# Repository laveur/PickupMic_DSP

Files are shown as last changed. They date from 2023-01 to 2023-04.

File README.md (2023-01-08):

# PickupMic_DSP
A Pickup Mic (Piezo) DSP Board

## Info
Based on a STM32F405 MCU, this allows you to connect up to four Piezo (Pickup Mics) To it and do some signal processing on it.

Produce_DanZhi SMT_Snapshot Top 2263802A_Y28 SMT02301071084998

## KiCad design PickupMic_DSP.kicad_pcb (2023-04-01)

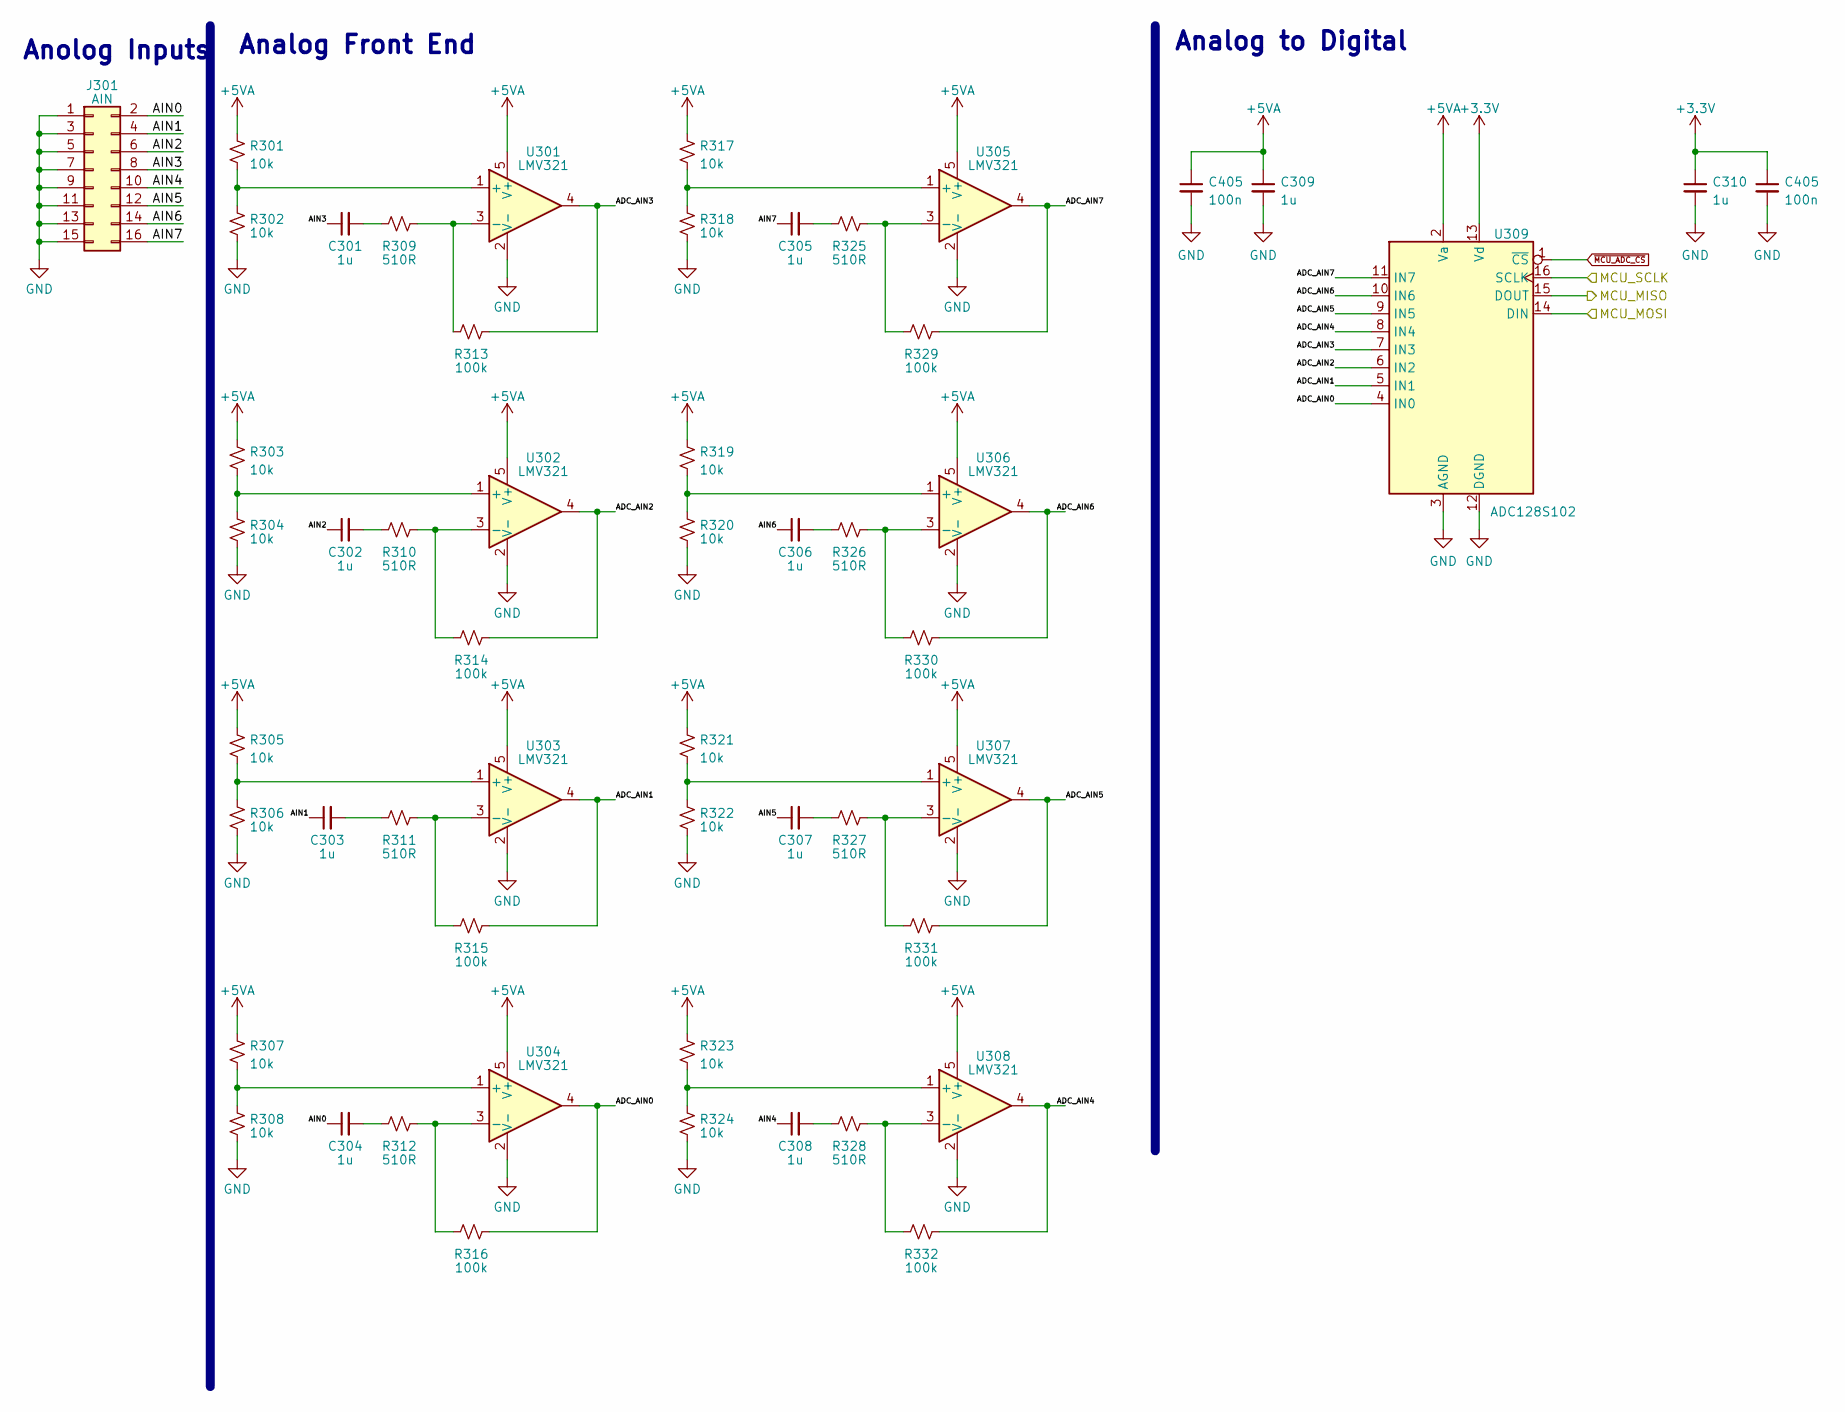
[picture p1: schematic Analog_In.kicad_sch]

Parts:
C301, C302, C303, C304, C305, C306, C307, C308, C309, C310: 1u; C_0402_1005Metric; LCSC C52923
C405: 100n; C_0402_1005Metric; LCSC C307331
J301: AIN; PinHeader_2x08_P2.54mm_Vertical
R301, R302, R303, R304, R305, R306, R307, R308, R317, R318, R319, R320, R321, R322, R323, R324: 10k; R_0402_1005Metric; LCSC C144807
R309, R310, R311, R312, R325, R326, R327, R328: 510R; R_0402_1005Metric; LCSC C25123
R313, R314, R315, R316, R329, R330, R331, R332: 100k; R_0402_1005Metric; LCSC C25086
U301, U302, U303, U304, U305, U306, U307, U308: LMV321; SOT-23-5; LCSC C7972
U309: ADC128S102; TSSOP-16_4.4x5mm_P0.65mm; LCSC C179666

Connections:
/Analog In/ADC_AIN0: R316.2, U304.4, U309.4 (IN0)
/Analog In/ADC_AIN1: R315.2, U303.4, U309.5 (IN1)
/Analog In/ADC_AIN2: R314.2, U302.4, U309.6 (IN2)
/Analog In/ADC_AIN4: R332.2, U308.4, U309.8 (IN4)
/Analog In/ADC_AIN5: R331.2, U307.4, U309.9 (IN5)
/Analog In/ADC_AIN6: R330.2, U306.4, U309.10 (IN6)
/Analog In/ADC_AIN7: R329.2, U305.4, U309.11 (IN7)
/Analog In/AIN0: C304.1, J301.2
/Analog In/AIN1: C303.1, J301.4
/Analog In/AIN2: C302.1, J301.6
/Analog In/AIN3: C301.1, J301.8
/Analog In/AIN4: C308.1, J301.10
/Analog In/AIN5: C307.1, J301.12
/Analog In/AIN6: C306.1, J301.14
/Analog In/AIN7: C305.1, J301.16
/Analog In/MCU_MISO: U309.15 (DOUT); also elsewhere on the board
/Analog In/MCU_MOSI: U309.14 (DIN); also elsewhere on the board
/Analog In/MCU_SCLK: U309.16 (SCLK); also elsewhere on the board
unnamed: C301.2, R309.2
unnamed: C302.2, R310.2
unnamed: C303.2, R311.2
unnamed: C304.2, R312.2
unnamed: C305.2, R325.2
unnamed: C306.2, R326.2
unnamed: C307.2, R327.2
unnamed: C308.2, R328.2
unnamed: R301.2, R302.2, U301.1 (+)
unnamed: R303.2, R304.1, U302.1 (+)
unnamed: R310.1, R314.1, U302.3 (-)
unnamed: R305.2, R306.2, U303.1 (+)
unnamed: R311.1, R315.1, U303.3 (-)
unnamed: R307.2, R308.2, U304.1 (+)
unnamed: R312.1, R316.1, U304.3 (-)
unnamed: R317.2, R318.2, U305.1 (+)
unnamed: R325.1, R329.1, U305.3 (-)
unnamed: R319.2, R320.2, U306.1 (+)
unnamed: R326.1, R330.1, U306.3 (-)
unnamed: R321.2, R322.2, U307.1 (+)
unnamed: R327.1, R331.1, U307.3 (-)
unnamed: R323.2, R324.2, U308.1 (+)
unnamed: R328.1, R332.1, U308.3 (-)
~MCU_ADC_CS: U309.1 (~CS); also elsewhere on the board

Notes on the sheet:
Analog Front End
Analog to Digital
Anolog Inputs

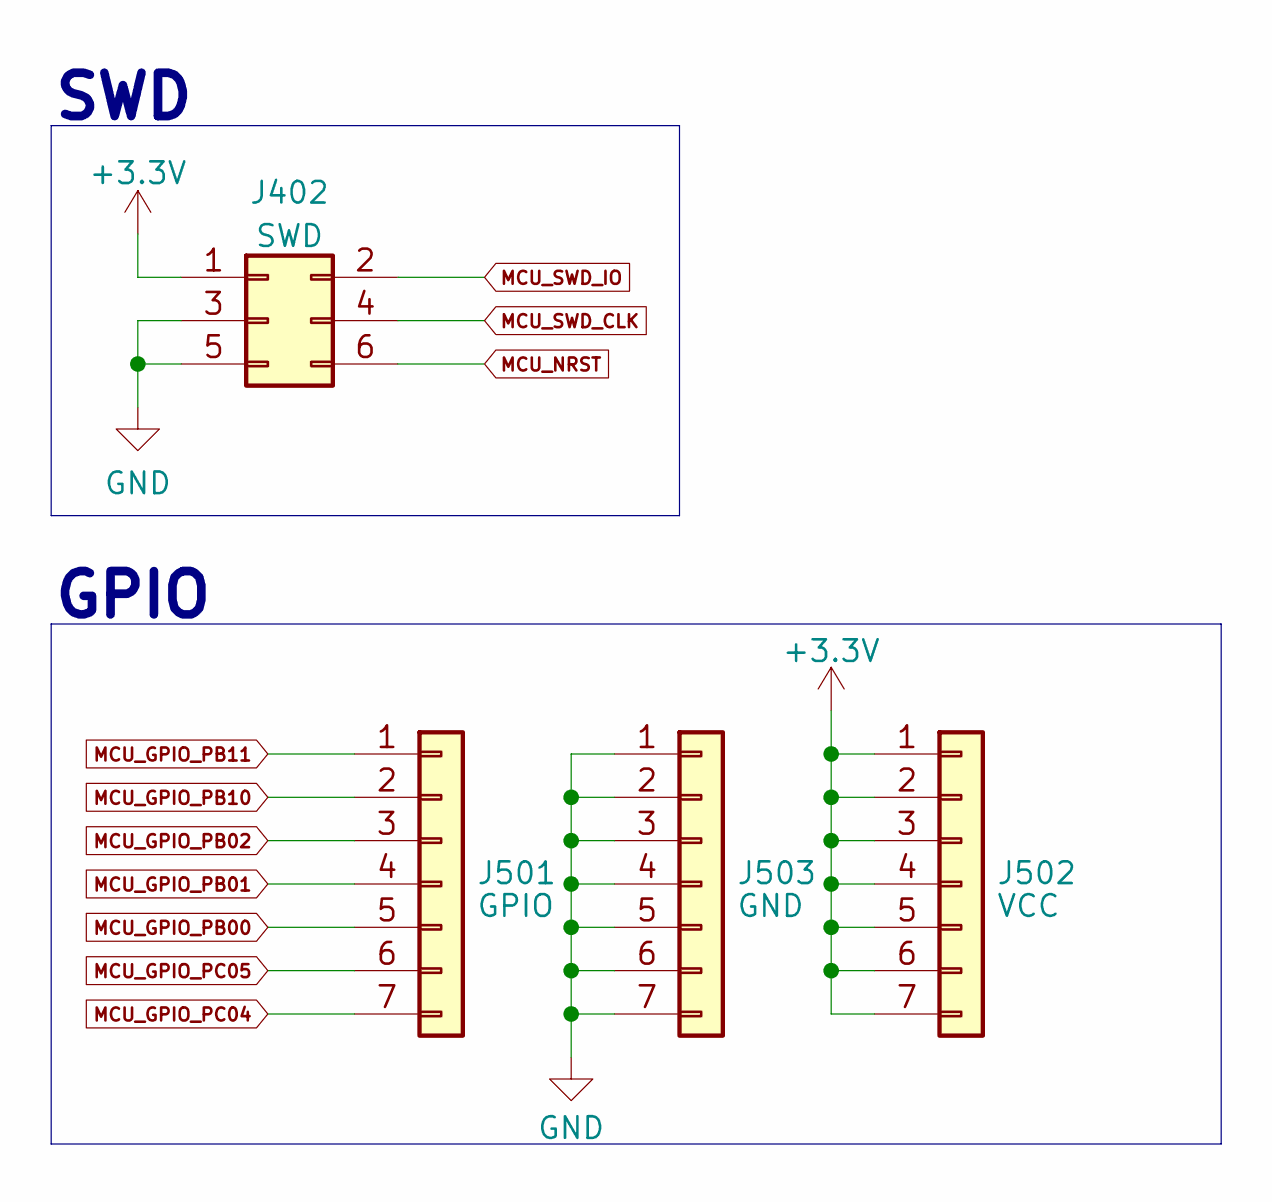
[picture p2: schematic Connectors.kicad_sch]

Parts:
J402: SWD; PinHeader_2x03_P2.54mm_Vertical
J501: GPIO; PinHeader_1x07_P2.54mm_Vertical
J502: VCC; PinHeader_1x07_P2.54mm_Vertical
J503: GND; PinHeader_1x07_P2.54mm_Vertical

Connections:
MCU_GPIO_PB00: J501.5; also elsewhere on the board
MCU_GPIO_PB01: J501.4; also elsewhere on the board
MCU_GPIO_PB02: J501.3; also elsewhere on the board
MCU_GPIO_PB10: J501.2; also elsewhere on the board
MCU_GPIO_PB11: J501.1; also elsewhere on the board
MCU_GPIO_PC04: J501.7; also elsewhere on the board
MCU_GPIO_PC05: J501.6; also elsewhere on the board

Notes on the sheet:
SWD
GPIO

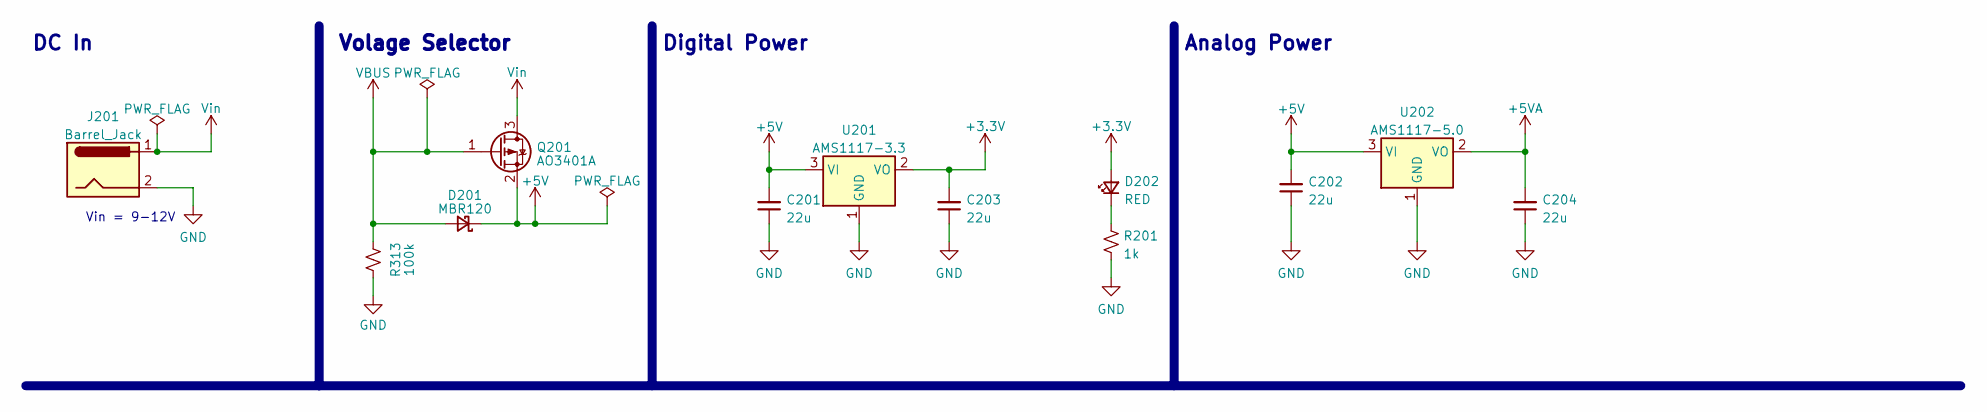
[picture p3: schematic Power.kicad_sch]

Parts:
C201, C202, C203, C204: 22u; C_0805_2012Metric; LCSC C45783
D201: MBR120; D_SOD-123; LCSC C130880
D202: RED; LED_0805_2012Metric; LCSC C84256
J201: Barrel_Jack; BarrelJack_Horizontal
Q201: AO3401A; SOT-23
R201: 1k; R_0603_1608Metric; LCSC C105580
R313: 100k; R_0402_1005Metric; LCSC C25086
U201: AMS1117-3.3; SOT-223-3_TabPin2; LCSC C6186
U202: AMS1117-5.0; SOT-223-3_TabPin2; LCSC C6187

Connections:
+5V: C201.2, C202.2, D201.1 (K), Q201.2 (S), U201.3 (VI), U202.3 (VI)
unnamed: D202.1 (K), R201.1
Vin: J201.1, Q201.3 (D)

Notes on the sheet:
Analog Power
Vin = 9-12V
Volage Selector
DC In
Digital Power

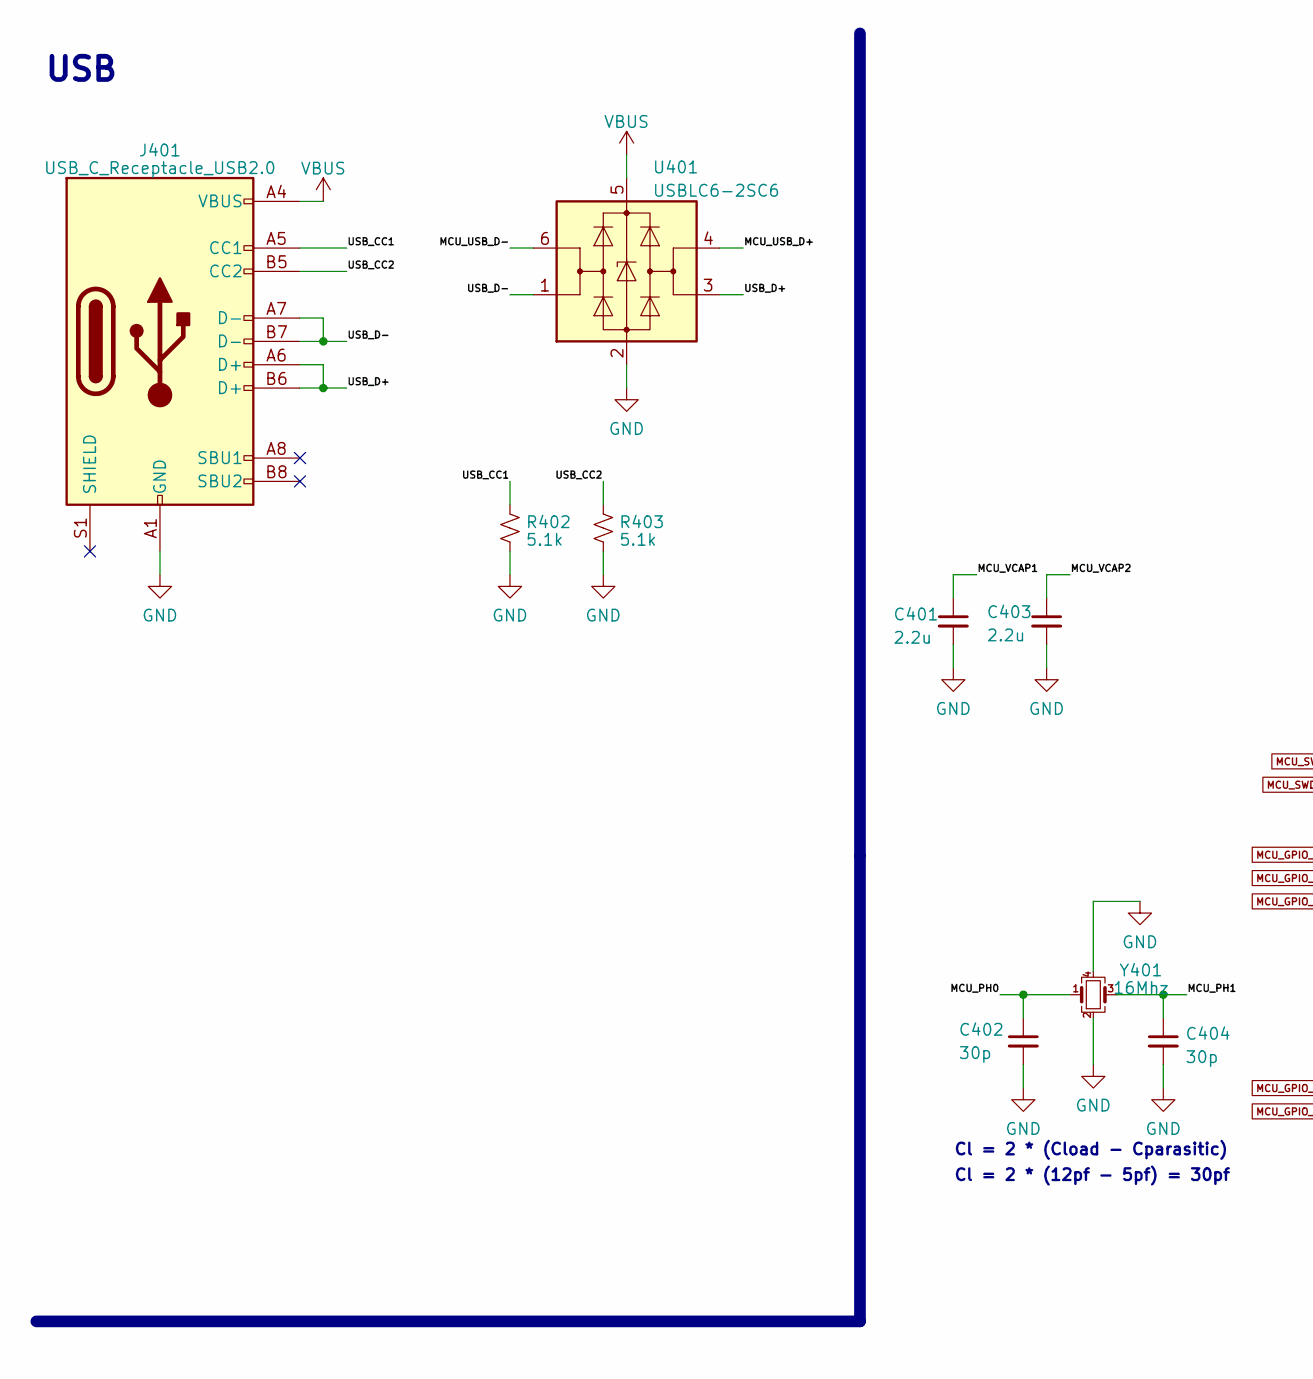
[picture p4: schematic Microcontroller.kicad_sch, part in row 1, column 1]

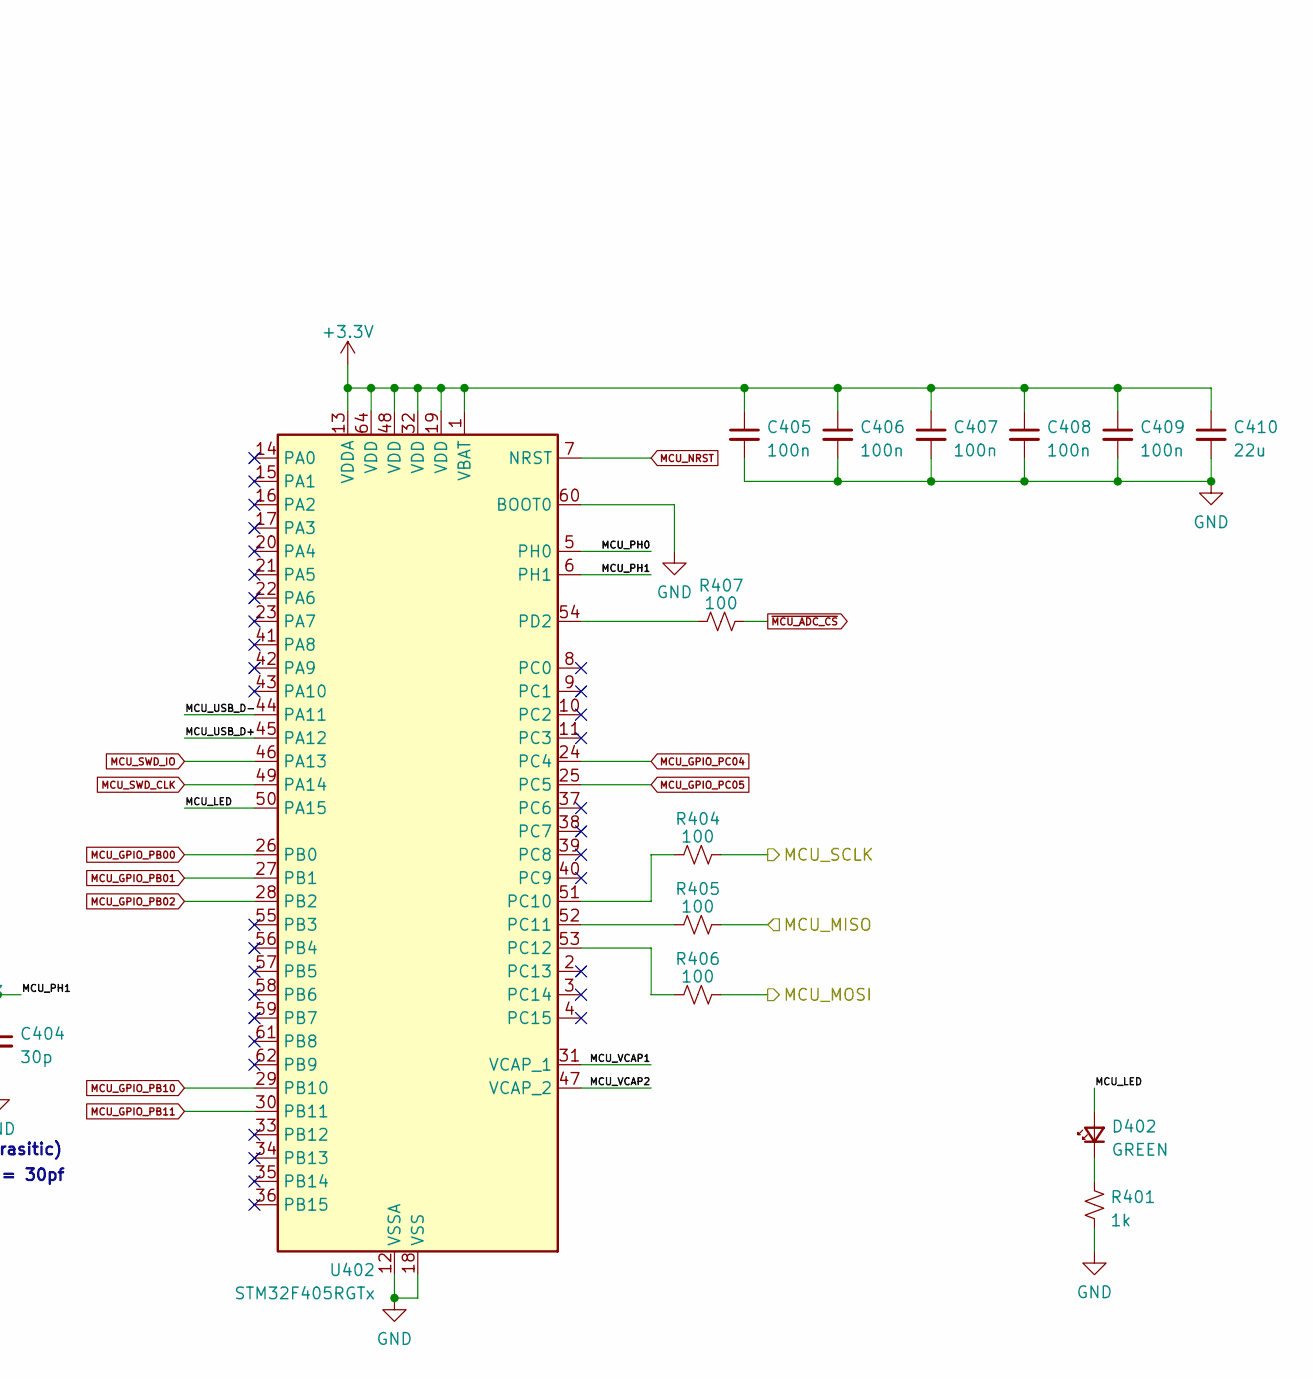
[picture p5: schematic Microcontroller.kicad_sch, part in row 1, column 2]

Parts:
C401, C403: 2.2u; C_0603_1608Metric; LCSC C106853
C402, C404: 30p; C_0603_1608Metric; LCSC C1658
C405, C406, C407, C408, C409: 100n; C_0603_1608Metric; LCSC C105907
C410: 22u; C_0805_2012Metric; LCSC C45783
D402: GREEN; LED_0805_2012Metric; LCSC C142303
J401: USB_C_Receptacle_USB2.0; USB_C_Receptacle_G-Switch_GT-USB-7010ASV; LCSC C2927037
R401: 1k; R_0603_1608Metric; LCSC C105580
R402, R403: 5.1k; R_0603_1608Metric; LCSC C23186
R404, R405, R406, R407: 100; R_0603_1608Metric; LCSC C22775
U401: USBLC6-2SC6; SOT-23-6; LCSC C2827654
U402: STM32F405RGTx; LQFP-64_10x10mm_P0.5mm; LCSC C15742
Y401: 16Mhz; Crystal_SMD_3225-4Pin_3.2x2.5mm; LCSC C133336

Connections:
/Analog In/MCU_MISO: R405.2; also elsewhere on the board
/Analog In/MCU_MOSI: R406.2; also elsewhere on the board
/Analog In/MCU_SCLK: R404.2; also elsewhere on the board
/Microcontroller/MCU_LED: D402.2 (A), U402.50 (PA15)
/Microcontroller/MCU_PH0: C402.1, U402.5 (PH0), Y401.1
/Microcontroller/MCU_PH1: C404.1, U402.6 (PH1), Y401.3
/Microcontroller/MCU_USB_D+: U401.4 (I/O2), U402.45 (PA12)
/Microcontroller/MCU_USB_D-: U401.6 (I/O1), U402.44 (PA11)
/Microcontroller/MCU_VCAP1: C401.1, U402.31 (VCAP_1)
/Microcontroller/MCU_VCAP2: C403.1, U402.47 (VCAP_2)
/Microcontroller/USB_CC1: J401.A5 (CC1), R402.1
/Microcontroller/USB_CC2: J401.B5 (CC2), R403.1
/Microcontroller/USB_D+: J401.A6 (D+), J401.B6 (D+), U401.3 (I/O2)
/Microcontroller/USB_D-: J401.A7 (D-), J401.B7 (D-), U401.1 (I/O1)
MCU_GPIO_PB00: U402.26 (PB0); also elsewhere on the board
MCU_GPIO_PB01: U402.27 (PB1); also elsewhere on the board
MCU_GPIO_PB02: U402.28 (PB2); also elsewhere on the board
MCU_GPIO_PB10: U402.29 (PB10); also elsewhere on the board
MCU_GPIO_PB11: U402.30 (PB11); also elsewhere on the board
MCU_GPIO_PC04: U402.24 (PC4); also elsewhere on the board
MCU_GPIO_PC05: U402.25 (PC5); also elsewhere on the board
MCU_NRST: U402.7 (NRST); also elsewhere on the board
MCU_SWD_CLK: U402.49 (PA14); also elsewhere on the board
MCU_SWD_IO: U402.46 (PA13); also elsewhere on the board
unnamed: D402.1 (K), R401.1
unnamed: R404.1, U402.51 (PC10)
unnamed: R405.1, U402.52 (PC11)
unnamed: R406.1, U402.53 (PC12)
unnamed: R407.1, U402.54 (PD2)
~MCU_ADC_CS: R407.2; also elsewhere on the board

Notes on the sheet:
Cl = 2 * (12pf - 5pf) = 30pf
Cl = 2 * (Cload - Cparasitic)
USB

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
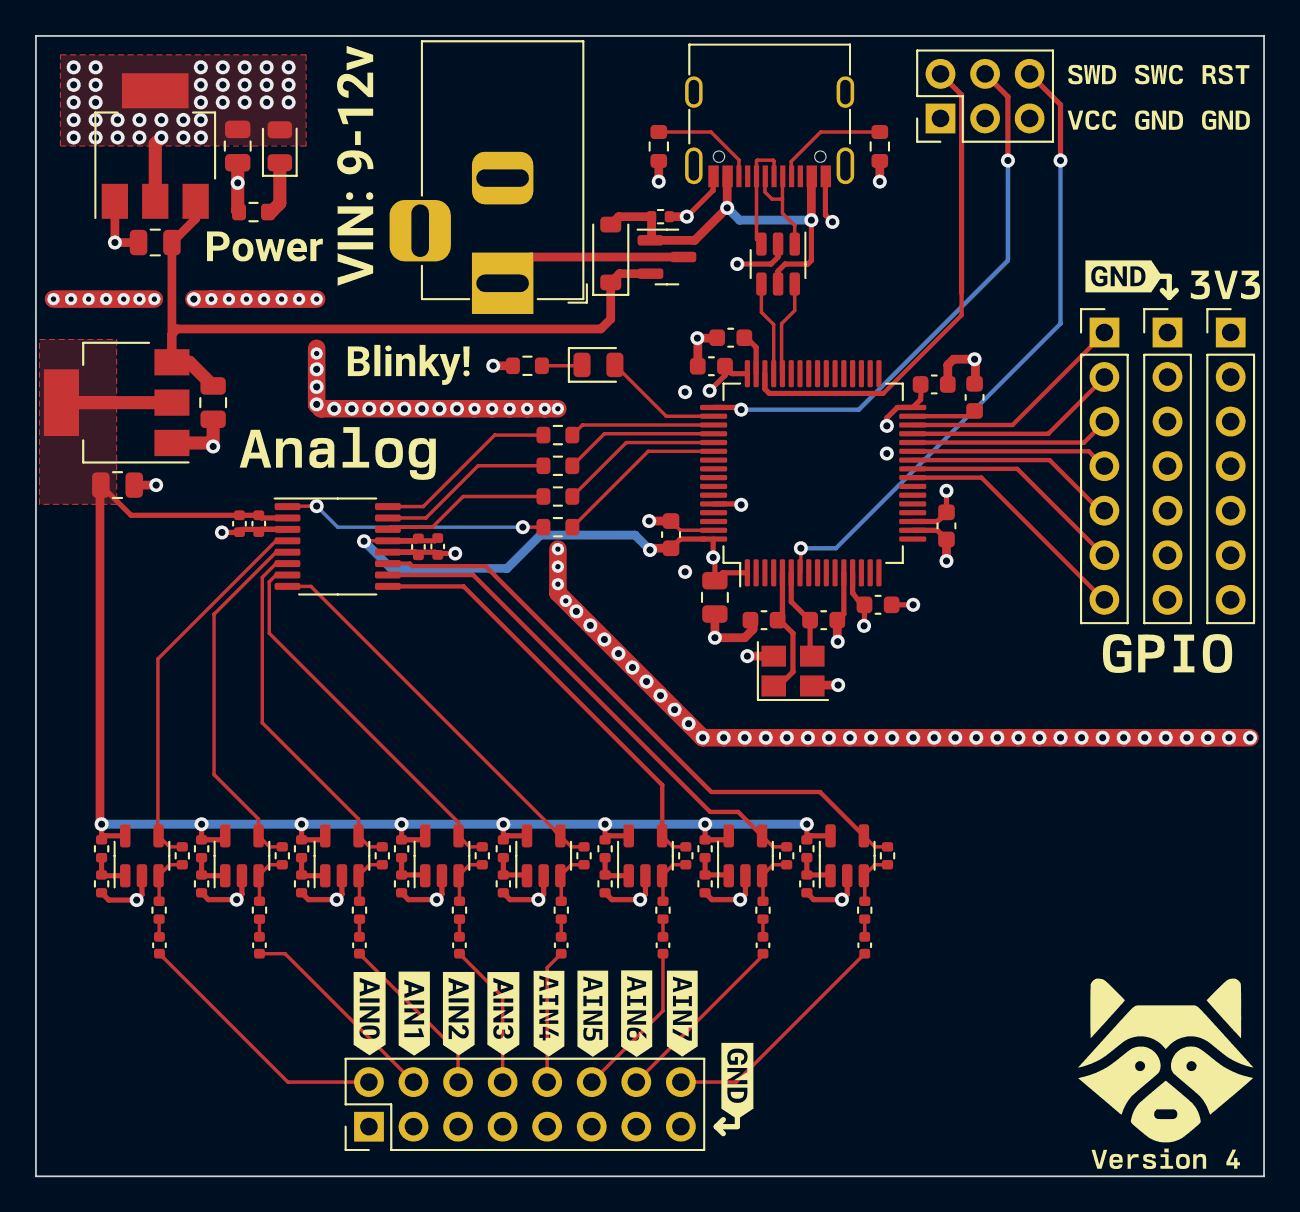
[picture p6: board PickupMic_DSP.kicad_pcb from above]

Board: 4 copper layers, 70.0 x 65.0 mm, 111 parts (0 on the bottom side), 77 nets.

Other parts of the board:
C311, C312: 100n; C_0402_1005Metric
J504: SWD; PinHeader_2x03_P2.54mm_Vertical
R202: 100k; R_0402_1005Metric
kibuzzard-63BB1A01: G***; kibuzzard-63BB1A01
kibuzzard-63BB1A7D: G***; kibuzzard-63BB1A7D
kibuzzard-63BB1A56: G***; kibuzzard-63BB1A56
kibuzzard-63BB1AB4, kibuzzard-63BB1AB4#2: G***; kibuzzard-63BB1AB4
kibuzzard-63BB1BAF: G***; kibuzzard-63BB1BAF
kibuzzard-63C77ADE: G***; kibuzzard-63C77ADE
kibuzzard-63C77B3E: G***; kibuzzard-63C77B3E
kibuzzard-63CD6EAA: G***; kibuzzard-63CD6EAA
kibuzzard-641D0A5C: G***; kibuzzard-641D0A5C
kibuzzard-641D0A72: G***; kibuzzard-641D0A72
kibuzzard-641D0A85: G***; kibuzzard-641D0A85
kibuzzard-641E03D9: G***; kibuzzard-641E03D9
kibuzzard-6422FB8B: G***; kibuzzard-6422FB8B
kibuzzard-6422FF5E: G***; kibuzzard-6422FF5E
kibuzzard-6423A41B: G***; kibuzzard-6423A41B
kibuzzard-6423A336: G***; kibuzzard-6423A336
kibuzzard-6423A404: G***; kibuzzard-6423A404
kibuzzard-642304B8: G***; kibuzzard-642304B8

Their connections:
MCU_NRST: J504.6; also elsewhere on the board
MCU_SWD_CLK: J504.4; also elsewhere on the board
MCU_SWD_IO: J504.2; also elsewhere on the board

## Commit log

2023-01-08 Initial Commit
    Added Kicad Project files
    [Analog_In.kicad_sch, Connectors.kicad_sch, Microcontroller.kicad_sch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]
2023-01-08 Small Updates
    * Updated GIT Ignore file to ignore the backups dir.
    * Added missing USB Micro 3D model.
    [PickupMic_DSP.kicad_pcb]
2023-01-23 Switch ADC
    Switched from the ADS1115 to ADS7924 to get faster sampling time.
    [Analog_In.kicad_sch, Microcontroller.kicad_sch, PickupMic_DSP.kicad_pcb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]
2023-04-01 Improvements
    Switched ADC to ADC128S.
    Upgraded USB to USB-C
    Improved Analog front end to work with signals better.
    [Analog_In.kicad_sch, Connectors.kicad_sch, Microcontroller.kicad_sch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]
